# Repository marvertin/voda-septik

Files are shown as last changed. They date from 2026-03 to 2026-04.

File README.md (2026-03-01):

# voda-septik

## Dokumentace

- [OTA aktualizace](docs/ota.md)
- [Logovani a log levely](docs/logging.md)

## Kalibrace tlaku (webapp)

Modul tlaku (`main/tlak.cpp`) meri dve 4-20 mA cidla (pred filtrem / za filtrem) a hodnoty mapuje pres kalibracni polozky dostupne v konfiguracni webapp.

- `tlk_b_raw_4ma` (default `745`) - ADC RAW hodnota pred filtrem odpovidajici 4 mA.
- `tlk_b_raw_20ma` (default `3722`) - ADC RAW hodnota pred filtrem odpovidajici 20 mA.
- `tlk_b_p_min` (default `0.0`) - tlak pred filtrem [bar] pro 4 mA.
- `tlk_b_p_max` (default `10.0`) - tlak pred filtrem [bar] pro 20 mA.
- `tlk_a_raw_4ma` (default `745`) - ADC RAW hodnota za filtrem odpovidajici 4 mA.
- `tlk_a_raw_20ma` (default `3722`) - ADC RAW hodnota za filtrem odpovidajici 20 mA.
- `tlk_a_p_min` (default `0.0`) - tlak za filtrem [bar] pro 4 mA.
- `tlk_a_p_max` (default `10.0`) - tlak za filtrem [bar] pro 20 mA.
- `tlk_ema_alpha` (default `0.55`) - spolecny EMA filtr pro obe cidla.
- `tlk_hyst_bar` (default `0.02`) - spolecna hystereze [bar] pro obe cidla.
- `tlk_sample_ms` (default `100`) - spolecna perioda mereni [ms] pro obe cidla.
- `tlk_round_dec` (default `2`) - spolecny pocet desetinnych mist publikovaneho tlaku.
- `tlk_dp_100` (default `1.0`) - rozdil tlaku [bar], ktery odpovida 100 % zanesenosti filtru.

Publikovane MQTT hodnoty:
- `stav/tlak/pred_filtrem_bar`
- `stav/tlak/za_filtrem_bar`
- `stav/tlak/rozdil_filtru_bar`
- `stav/tlak/zanesenost_filtru_percent`

Doporuceny postup prvotniho nastaveni:
1. Pro kazde cidlo zvlast zmerit referencni body 4 mA/20 mA a upravit `tlk_b_*` a `tlk_a_*`.
2. Nastavit realny rozsah cidel (vychozi 0-10 bar) pomoci `tlk_b_p_min/max` a `tlk_a_p_min/max`.
3. Podle dynamiky provozu doladit spolecnou filtraci (`tlk_ema_alpha`, `tlk_hyst_bar`, `tlk_sample_ms`, `tlk_round_dec`).
4. Podle provozu filtru doladit `tlk_dp_100`, aby procenta zaneseni odpovidala realnemu stavu.

Kalibracni checklist (rychly postup):
- [ ] Zapnout debug pro tag `TLAK` a overit, ze hodnoty `raw` nekolisaji nestandardne.
- [ ] Pri referencnim bode 4 mA/20 mA nastavit kalibraci pred filtrem (`tlk_b_*`).
- [ ] Pri referencnim bode 4 mA/20 mA nastavit kalibraci za filtrem (`tlk_a_*`).
- [ ] Overit, ze tlaky odpovidaji manometru, pripadne doladit `tlk_b_p_min/max` a `tlk_a_p_min/max`.
- [ ] Doladit spolecnou filtraci (`tlk_ema_alpha`, `tlk_hyst_bar`, `tlk_sample_ms`, `tlk_round_dec`) podle pozadovane dynamiky.
- [ ] Pri znamem zanesenem stavu filtru doladit `tlk_dp_100`.

## Kalibrace objemu (webapp)

Modul objemu (`main/zasoba.cpp`) interne zmeri vysku hladiny (kalibrace `lvl_*`) a do MQTT/HA publikuje objem i vysku hladiny.

Kalibracni polozky:
- `lvl_raw_min` (default `540`) - ADC RAW hodnota odpovidajici minimalni hladine.
- `lvl_raw_max` (default `950`) - ADC RAW hodnota odpovidajici maximalni hladine.
- `lvl_h_min` (default `0.0`) - vyska hladiny [m] pro `lvl_raw_min`.
- `lvl_h_max` (default `0.290`) - vyska hladiny [m] pro `lvl_raw_max`.
- `tank_area_m2` (default `5.4`) - pudorysna plocha nadrze [m²] (pro nadrz 2 × 2.7 m).

Pouzity prepocet:
- vyska z kalibrace RAW: linearni mapovani mezi `lvl_raw_min/lvl_raw_max` a `lvl_h_min/lvl_h_max`
- objem: `objem_l = vyska_m * tank_area_m2 * 1000`

Publikovany MQTT vystup:
- `stav/zasoba/objem_l` [l]
- `stav/zasoba/hladina_m` [m]

Prakticky postup:
1. Nejdriv zkalibrovat vysku (`lvl_*`) podle realnych referencnich bodu.
2. Nastavit skutecnou plochu nadrze v `tank_area_m2`.
3. Overit v HA, ze `stav/zasoba/objem_l` a `stav/zasoba/hladina_m` odpovidaji realnemu stavu nadrze.

## Struktura mqtt topiků.

Poznamka (migrace):
- Konfiguracni polozka `mqtt_topic` byla odstranena.
- Korenny topic je nyni pevne dany v registru topiku (`main/mqtt_topics.*`) jako `voda/septik`.

## Home Assistant MQTT discovery

- Firmware po kazdem pripojeni k MQTT automaticky publikuje discovery konfiguraci pro vsechny `PUBLISH_ONLY` topicy.
- Discovery konfigurace jsou publikovane jako retained zpravy pod vetvi `homeassistant/.../config`.
- Device je seskupene pod identifikatorem `voda_septik_esp32`.
- Pro odebrani starych entit je potreba smazat retained discovery topicy na brokeru.

```
voda/septik                         Voda v nadrzi (byvaly septik), vcetne dalsich budoucih pouziti (napr. bazen)

├── stav/
│    ├── teplota/
│    │    ├── voda                  [°C] Aktuální teplota vody v nádrži. HA: sensor (device_class: temperature)
│    │    └── vzduch                [°C] Aktuální teplota vzduchu v šachtě u potrubí v blízkosti tlakové nádoby. HA: sensor (device_class: temperature)
│    ├── zasoba/
│    │    ├── objem_l               [l] Aktuální objem vody v nádrži. HA: sensor (state_class: measurement)
│    │    └── hladina_m             [m] Aktuální výška hladiny vody v nádrži. HA: sensor (state_class: measurement)
│    ├── cerpani/
│    │    ├── prutok_l_min          [l/min] Aktuální průtok vody. HA: sensor (state_class: measurement)
│    │    ├── cerpano_celkem_l      [l] Celkové vyčerpané množství vody od počátku. HA: sensor (state_class: total_increasing)
│    │    └── pumpa/
│    │         ├── bezi             [bool] Příznak ano/ne (0/1), zda čerpadlo běží. HA: binary_sensor (device_class: running)
│    │         ├── vykon_cinny_w    [W] Aktuální činný výkon. HA: sensor (device_class: power)
│    │         ├── jalovy_vykon_var [var] Aktuální jalový výkon. HA: sensor
│    │         ├── cosfi            [-] Aktuální účiník. HA: sensor
│    │         ├── proud_a          [A] Aktuální proud protékaný čerpadlem. HA: sensor (device_class: current)
│    │         ├── napeti_v         [V] Aktuální napětí na čerpadle. HA: sensor (device_class: voltage)
│    │         ├── energie_cinna_kwh [kWh] Celkové množství spotřebované činné energie. HA: sensor (device_class: energy, state_class: total_increasing)
│    │         └── energie_jalova_kvarh [kvarh] Celkové množství spotřebované jalové energie. HA: sensor (state_class: total_increasing)
│    └── tlak/
│         ├── pred_filtrem_bar      [bar] Aktuální tlak vody před filtrem. HA: sensor (device_class: pressure)
│         ├── za_filtrem_bar        [bar] Aktuální tlak vody za filtrem. HA: sensor (device_class: pressure)
│         ├── rozdil_filtru_bar     [bar] Rozdíl tlaku před a za filtrem. HA: sensor (state_class: measurement)
│         └── zanesenost_filtru_percent [%] Odhad zanesení filtru v procentech (odvozeno z rozdílu tlaků). HA: sensor
│
├── system/
│    ├── status                     [-] online/offline (řešeno přes LWT). HA: binary_sensor (device_class: connectivity)
│    ├── boot_mode                  [text] Rezim startu firmware: `ota` (pending verify) / `normal`
│    ├── ota/event                  [text] Prubeh OTA operace (start/download/rebooting/confirmed/error_...)
│    ├── ota/progress               [%] Prubeh OTA stahovani a zapisu (0-100)
│    ├── reboot_reason              [text] Důvod posledního rebootu (esp_reset_reason). HA: sensor
│    ├── reboot_counter             [count] Počet rebootů od instalace. HA: sensor (state_class: total_increasing)
│    └── last_disconnect_duration_s [s] Doba posledního výpadku spojení. HA: sensor
│
├── diag/
│    ├── fw_version                 [text] Verze firmware. HA: sensor
│    ├── build_timestamp            [datetime] Datum a čas sestavení firmware. HA: sensor
│    ├── git_hash                   [text] Git hash verze firmware. HA: sensor
│    ├── uptime_s                   [s] Jak dlouho zařízení běží. HA: sensor (state_class: total_increasing)
│    ├── wifi_rssi_dbm              [dBm] Síla WiFi signálu. HA: sensor (device_class: signal_strength)
│    ├── wifi_reconnect_try         [count] Počet pokusů o reconnect k WiFi. HA: sensor (state_class: total_increasing)
│    ├── wifi_reconnect_success     [count] Počet úspěšných reconnectů k WiFi. HA: sensor (state_class: total_increasing)
│    ├── mqtt_reconnects            [count] Počet reconnectů k MQTT brokeru. HA: sensor (state_class: total_increasing)
│    ├── last_mqtt_rc               [code] Poslední návratový kód MQTT klienta. HA: sensor
│    ├── heap_free_b                [B] Aktuální počet volných bajtů na heapu. HA: sensor (device_class: data_size)
│    ├── heap_min_free_b            [B] Nejmenší zaznamenaná hodnota volného heapu od startu. HA: sensor (device_class: data_size)
│    ├── esp_vcc_mv                 [mV] Napájecí napětí ESP. HA: sensor (device_class: voltage)
│    ├── nvs_errors                 [count] Počet chyb při práci s NVS. HA: sensor (state_class: total_increasing)
│    └── teplota_scan               [json] Prubezny report nalezenych DS18B20 adres, teplot a mapovani na konfiguraci
│
├── cmd/
│    ├── reboot                     [-] Reboot zařízení, čímž se vypnou všechny debugy. HA: button
│    ├── webapp/start               [-] Nastartování konfigurační aplikace. Implicitně je vypnutá, po startu se sama po 2 hodinách vypne. HA: button
│    ├── webapp/stop                [-] Vypnutí webové aplikace. HA: button
│    ├── debug/start                [-] Nastartování debug režimu, začnou se produkovat debug data. HA: button
│    ├── debug/stop                 [-] Zastavení debug režimu. HA: button
│    ├── log/level                  [text] Nastaveni log levelu per tag (payload: tag=level)
│    ├── ota/start                  [url] URL na binarni obraz firmware (http/https)
│    ├── ota/confirm                [-] Rucni potvrzeni nahraneho firmware po overeni funkcnosti
│    └── teplota/scan               [bool] Zapnuti/vypnuti periodickeho skenovani DS18B20 adres (1=true, 0=false)
│
└── debug

## Ovladani pres Mosquitto CLI

Podrobny navod k logovani je v dokumentu [Logovani a log levely](docs/logging.md).

Pro pohodlne ovladani je v projektu jednotny interaktivni skript:

```bash
zalevaci
```

Pokud jeste nemas aktivni `direnv`, udelej jednorazove:

```bash
direnv allow
```

Potom bude `tools/` automaticky v `PATH` pri vstupu do adresare projektu a prikaz `zalevaci` bude dostupny primo.

Napoveda a neinteraktivni rezim:

```bash
zalevaci --help
```

Priklady (vhodne pro skripty/CI):

```bash
# command publish
zalevaci cmd reboot

# log level
zalevaci log --tag mqtt_cmd --level DEBUG

# vycisteni retained cmd topiku
zalevaci clear-retained

# vypis nalezenych log tagu
zalevaci tags
```

Skript:
- pouziva default parametry: `mqtt.home.arpa:1883`, uzivatel `ha`, `qos=1`, root `voda/septik`,
- cte heslo ze souboru `~/.voda-septik/mqtt_password`,
- kdyz soubor neexistuje, zepta se na heslo a ulozi ho (`chmod 600`),
- nabidne menu pro command topiky (`reboot`, `webapp/start`, `debug/start|stop`, ...),
- umi nastavit log level (vcetne volby tagu nalezenych ve zdrojacich),
- umi zapnout/vypnout scan teplotnich cidel (`cmd/teplota/scan`),
- umi vycistit retained command topiky,
- umi projit OTA flow (HTTP server + `cmd/ota/start` + potvrzeni).

Volitelne lze prepsat parametry pres promenne prostredi:

```bash
MQTT_HOST=mqtt.home.arpa MQTT_PORT=1883 MQTT_USER=ha TOPIC_ROOT=voda/septik zalevaci
```

Pokud je potreba smazat stare retained command zpravy na brokeru, pouzij volbu `Vycistit retained cmd/*` v menu skriptu `zalevaci`.

Nize jsou priklady pro `mosquitto_sub` a `mosquitto_pub`.

Nejdriv si nastav promenne (uprav podle sveho brokeru):

```bash
MQTT_HOST=192.168.1.10
MQTT_PORT=1883
MQTT_USER="uzivatel"
MQTT_PASS="heslo"
TOPIC_ROOT="voda/septik"
```

### Odběr vsech dat ze zarizeni

```bash
mosquitto_sub -h "$MQTT_HOST" -p "$MQTT_PORT" -u "$MQTT_USER" -P "$MQTT_PASS" -v -t "$TOPIC_ROOT/#"
```

### Odeslani commandu

`cmd/reboot` (restart zarizeni):

```bash
mosquitto_pub -h "$MQTT_HOST" -p "$MQTT_PORT" -u "$MQTT_USER" -P "$MQTT_PASS" -t "$TOPIC_ROOT/cmd/reboot" -m "1"
```

`cmd/webapp` (spusti konfiguracni web):

```bash
mosquitto_pub -h "$MQTT_HOST" -p "$MQTT_PORT" -u "$MQTT_USER" -P "$MQTT_PASS" -t "$TOPIC_ROOT/cmd/webapp" -m "on"
```

`cmd/webapp` (zastavi konfiguracni web):

```bash
mosquitto_pub -h "$MQTT_HOST" -p "$MQTT_PORT" -u "$MQTT_USER" -P "$MQTT_PASS" -t "$TOPIC_ROOT/cmd/webapp" -m "off"
```

`cmd/debug` (zapne debug publikaci):

```bash
mosquitto_pub -h "$MQTT_HOST" -p "$MQTT_PORT" -u "$MQTT_USER" -P "$MQTT_PASS" -t "$TOPIC_ROOT/cmd/debug" -m "on"
```

`cmd/debug` (vypne debug publikaci):

```bash
mosquitto_pub -h "$MQTT_HOST" -p "$MQTT_PORT" -u "$MQTT_USER" -P "$MQTT_PASS" -t "$TOPIC_ROOT/cmd/debug" -m "off"
```

`cmd/ota/start` (spusti OTA z URL):

```bash
mosquitto_pub -h "$MQTT_HOST" -p "$MQTT_PORT" -u "$MQTT_USER" -P "$MQTT_PASS" -q 1 -t "$TOPIC_ROOT/cmd/ota/start" -m "http://192.168.1.10:8000/voda-septik.bin"
```

`cmd/ota/confirm` (potvrdi novy firmware po rebootu):

```bash
mosquitto_pub -h "$MQTT_HOST" -p "$MQTT_PORT" -u "$MQTT_USER" -P "$MQTT_PASS" -q 1 -t "$TOPIC_ROOT/cmd/ota/confirm" -m "1"
```

`cmd/teplota/scan` (zapne periodicky scan DS18B20 adres a report na `diag/teplota_scan`):

```bash
mosquitto_pub -h "$MQTT_HOST" -p "$MQTT_PORT" -u "$MQTT_USER" -P "$MQTT_PASS" -q 1 -t "$TOPIC_ROOT/cmd/teplota/scan" -m "1"
```

`cmd/teplota/scan` (vypne scan):

```bash
mosquitto_pub -h "$MQTT_HOST" -p "$MQTT_PORT" -u "$MQTT_USER" -P "$MQTT_PASS" -q 1 -t "$TOPIC_ROOT/cmd/teplota/scan" -m "0"
```

### Odběr debug vetve

```bash
mosquitto_sub -h "$MQTT_HOST" -p "$MQTT_PORT" -u "$MQTT_USER" -P "$MQTT_PASS" -v -t "$TOPIC_ROOT/debug/#"
```

## OTA helper skript

Podrobny navod k OTA je v dokumentu [OTA aktualizace](docs/ota.md).

V projektu je interaktivni helper (soucast `zalevaci`), ktery:
- spusti jednoduchy HTTP server nad vybranym `.bin` souborem,
- posle MQTT command `cmd/ota/start` s URL na firmware,
- po rebootu se zepta, zda je firmware v poradku,
- pri potvrzeni posle `cmd/ota/confirm`.

Spusteni:

```bash
zalevaci
```

V menu zvol `OTA flow`.

## Architektura site (po refaktoru)

- `components/network_core/network_init.*`
    - Orchestrace site: WiFi init (STA/AP), MQTT lifecycle, event handlery, retry timery (neblokujici).
    - Sbira runtime data (wifi/ip/mqtt) a publikuje callback `network_event_t`.

- `components/network_core/network_event.*`
    - Definice `network_event_t` + vyhodnoceni `system_network_level_t`.
    - Vyroba sitoveho eventu primo uvnitr `network_core` vcetne reconnect counteru.

- `components/network_core/network_mqtt_config.*`
    - Validace `mqtt_uri` a bezpecne ulozeni `uri/user/pass` pro MQTT klienta.
    - Poskytuje read-only pristup na pripravenou konfiguraci.

- `components/network_core/mqtt_publish.*`
    - Samostatna vrstva pro publikaci zprav (`mqtt_publish`) mimo init/lifecycle.
    - Pouziva aktivni MQTT klient handle z `network_init`.

- `main/network_event_bridge.*`
    - Odebira `network_event_t` callback z `network_core`.
    - Bali jej do `app_event_t` a publikuje `EVT_NETWORK` do interni event queue.

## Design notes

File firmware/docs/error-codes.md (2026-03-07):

# Error kódy (`Exxx`) – mapování a pravidla

## Pravidla

- Formát kódu je `E` + 3 číslice.
- První číslice určuje modul (rozsah `E1xx` až `E9xx`).
- V rámci modulu se kódy přidělují postupně bez mezer (`E101`, `E102`, ...).
- Kódy musí být v projektu unikátní.
- `cpp_app_main` v `main/voda-septik.cpp` začíná na `E101`.

## Mapa modulů

| Modul | Soubory | Rozsah |
|---|---|---|
| `cpp_app_main` | `main/voda-septik.cpp` | `E101–E199` |
| `network_core` | `components/network_core/network_init.cpp` | `E201–E299` |
| `config_store` | `components/config_store/config_store.cpp` | `E301–E399` |
| `restart_info` | `main/restart_info.cpp` | `E401–E499` |
| `mqtt_runtime` | `main/mqtt_commands.cpp`, `main/mqtt_publisher_task.cpp` | `E501–E599` |
| `state_manager` | `main/state_manager.cpp` | `E601–E699` |
| `sensor_stack` | `main/adc_shared.cpp`, `main/prutokomer.cpp`, `main/teplota.cpp`, `main/tlak.cpp`, `main/tlak2.cpp`, `main/zasoba.cpp` | `E701–E799` |
| `config_items` | `main/network_config.cpp`, `main/system_config.cpp` | `E801–E899` |
| `display_lcd` | `main/lcd.cpp` | `E901–E999` |

## Kontrola duplicit

Použij projektové hledání na výraz `\bE\d{3}\b` a ověř, že každý kód je použit právě jednou.

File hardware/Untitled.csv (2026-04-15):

Název sítě | Třída sítí | Délka sítě (mm) | Počet prokovů | Délka prokovu (mm) | Délka spoje (mm) | Délka od plošky po čip (mm) | Počet plošek | F.Cu (mm) | B.Cu (mm)
GND | Napájení a Default | 434.6058 | 7 | 10.8150 | 423.7908 | 0.0000 | 32 | 166.2069 | 257.5838
+5V | Napájení a Default | 150.7235 | 1 | 1.5450 | 149.1785 | 0.0000 | 7 | 70.7569 | 78.4217
/hladina 4-20mA | Default | 29.7595 | 0 | 0.0000 | 29.7595 | 0.0000 | 3 | 0.0000 | 29.7595
/tlak_za_filtrem | Default | 15.5075 | 0 | 0.0000 | 15.5075 | 0.0000 | 3 | 0.0000 | 15.5075
/teploměry | Default | 19.2966 | 0 | 0.0000 | 19.2966 | 0.0000 | 3 | 0.0000 | 19.2966
/průtok | Default | 13.7500 | 0 | 0.0000 | 13.7500 | 0.0000 | 3 | 0.0000 | 13.7500
Net-(C1-Pad1) | Default | 11.1911 | 0 | 0.0000 | 11.1911 | 0.0000 | 2 | 0.0000 | 11.1911
Net-(D2-K) | Default | 51.5259 | 0 | 0.0000 | 51.5259 | 0.0000 | 6 | 0.0000 | 51.5259
Net-(D2-A) | Default | 11.3450 | 0 | 0.0000 | 11.3450 | 0.0000 | 2 | 0.5000 | 10.8450
Net-(D4-K) | Default | 48.0354 | 0 | 0.0000 | 48.0354 | 0.0000 | 4 | 0.0000 | 48.0354
Net-(D5-K) | Default | 40.9083 | 0 | 0.0000 | 40.9083 | 0.0000 | 4 | 0.0000 | 40.9083
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

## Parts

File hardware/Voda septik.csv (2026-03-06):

Reference | Qty | Value | DNP | Exclude from BOM | Exclude from Board | Footprint | Datasheet
BT1 | 1 | 3V |  |  |  | Battery:BatteryHolder_Keystone_1058_1x2032 | ~
D1 | 1 | red |  |  |  | LED_THT:LED_D5.0mm | ~
R1 | 1 | 1k |  |  |  | Resistor_THT:R_Axial_DIN0309_L9.0mm_D3.2mm_P12.70mm_Horizontal | ~

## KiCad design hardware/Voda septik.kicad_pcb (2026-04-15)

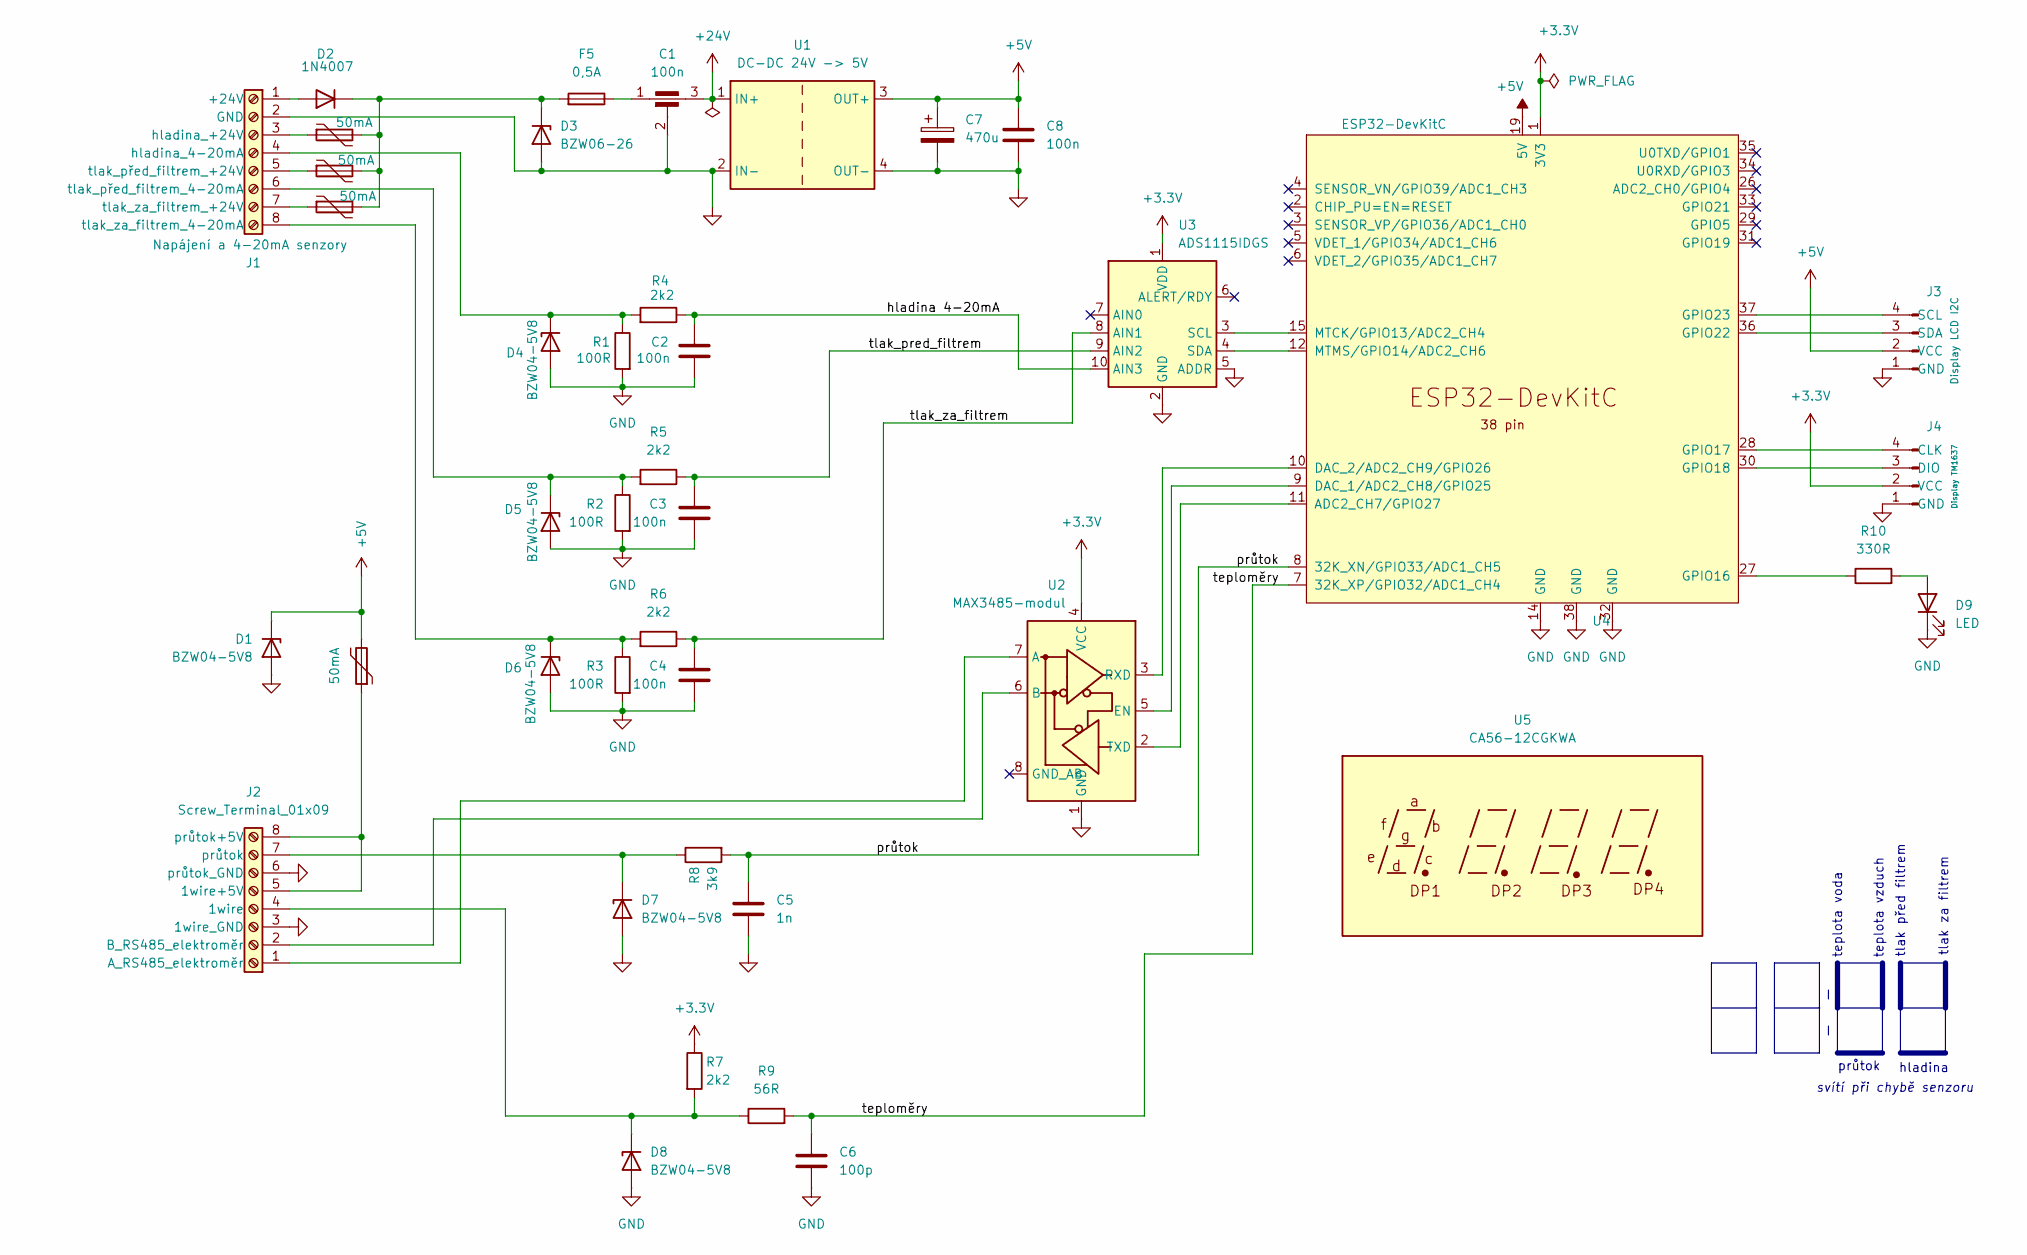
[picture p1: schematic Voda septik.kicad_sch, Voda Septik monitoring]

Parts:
C1: 100n; Odruseni_3x_2.54mm
C2, C3, C4, C8: 100n; C_Disc_D5.0mm_W2.5mm_P5.00mm
C5: 1n; C_Disc_D5.0mm_W2.5mm_P5.00mm
C6: 100p; C_Disc_D5.0mm_W2.5mm_P5.00mm
C7: 470u; CP_Radial_D10.0mm_P5.00mm
D1, D4, D5, D6, D7, D8: BZW04-5V8; D_DO-15_P2.54mm_Vertical_AnodeUp
D2: 1N4007; D_DO-15_P2.54mm_Vertical_AnodeUp
D3: BZW06-26; D_DO-15_P2.54mm_Vertical_AnodeUp
D9: LED; LED_D3.0mm
F1, F2, F3, F4: 50mA; Fuse_Disc_D8.3_W3.8_P5.1
F5: 0,5A; Fuse_Axial_L11mm_D3.9mm_P15.24mm_Horizontal
J1: Napájení a 4-20mA senzory; Svorky_EB147A_8_5.08
J2: Screw_Terminal_01x09; Svorky_EB147A_8_5.08
J3: Display LCD I2C; PinHeader_1x04_P2.54mm_Vertical
J4: Display TM1637; PinHeader_1x04_P2.54mm_Vertical
R1, R2, R3: 100R; R_Axial_DIN0207_L6.3mm_D2.5mm_P2.54mm_Vertical
R4, R5, R6, R7: 2k2; R_Axial_DIN0207_L6.3mm_D2.5mm_P2.54mm_Vertical
R8: 3k9; R_Axial_DIN0207_L6.3mm_D2.5mm_P2.54mm_Vertical
R9: 56R; R_Axial_DIN0207_L6.3mm_D2.5mm_P2.54mm_Vertical
R10: 330R; R_Axial_DIN0207_L6.3mm_D2.5mm_P2.54mm_Vertical
U1: DC-DC 24V -> 5V; LM2596 DC-DC HW-411
U2: MAX3485-modul
U3: ADS1115IDGS; ADS1115_modul_vertical
U4: ESP32-DevKitC
U5: CA56-12CGKWA; DISPLAY_clok_MOUNT_4xM3

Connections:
+3.3V: J4.2 (VCC), R7.1, U2.4 (VCC), U3.1 (VDD), U4.1 (3V3)
+5V: C7.1, C8.1, D1.1 (K), F4.2, J3.2 (VCC), U1.3 (OUT+), U4.19 (5V)
+24V: C1.3, U1.1 (IN+)
/hladina 4-20mA: C2.1, R4.1, U3.10 (AIN3)
/průtok: C5.1, R8.2, U4.8 (32K_XN/GPIO33/ADC1_CH5)
/teploměry: C6.1, R9.2, U4.7 (32K_XP/GPIO32/ADC1_CH4)
/tlak_za_filtrem: C4.1, R6.1, U3.8 (AIN1)
GND: C1.2, C2.2, C3.2, C4.2, C5.2, C6.2, C7.2, C8.2, D1.2 (A), D3.2 (A), D4.2 (A), D5.2 (A), D6.2 (A), D7.2 (A), D8.2 (A), D9.1 (K), J1.2 (GND), J2.3 (1wire_GND), J2.6 (průtok_GND), J3.1 (GND), J4.1 (GND), R1.2, R2.2, R3.2, U1.2 (IN-), U1.4 (OUT-), U2.1 (GND), U3.2 (GND), U3.5 (ADDR), U4.14 (GND), U4.32 (GND), U4.38 (GND)
unnamed: C1.1, F5.2
unnamed: D2.2 (A), J1.1 (+24V)
unnamed: D2.1 (K), D3.1 (K), F1.2, F2.2, F3.2, F5.1
unnamed: D4.1 (K), J1.4 (hladina_4-20mA), R1.1, R4.2
unnamed: D5.1 (K), J1.6 (tlak_před_filtrem_4-20mA), R2.1, R5.2
unnamed: D6.1 (K), J1.8 (tlak_za_filtrem_4-20mA), R3.1, R6.2
unnamed: D7.1 (K), J2.7 (průtok), R8.1
unnamed: D8.1 (K), J2.4 (1wire), R7.2, R9.1
unnamed: D9.2 (A), R10.2
unnamed: F1.1, J1.3 (hladina_+24V)
unnamed: F2.1, J1.5 (tlak_před_filtrem_+24V)
unnamed: F3.1, J1.7 (tlak_za_filtrem_+24V)
unnamed: F4.1, J2.5 (1wire+5V), J2.8 (průtok+5V)
unnamed: J2.1 (A_RS485_elektroměr), U2.7 (A)
unnamed: J2.2 (B_RS485_elektroměr), U2.6 (B)
unnamed: J3.4 (SCL), U4.37 (GPIO23)
unnamed: J3.3 (SDA), U4.36 (GPIO22)
unnamed: J4.4 (CLK), U4.28 (GPIO17)
unnamed: J4.3 (DIO), U4.30 (GPIO18)
unnamed: U2.5 (EN), U4.9 (DAC_1/ADC2_CH8/GPIO25)
unnamed: U2.3 (RXD), U4.10 (DAC_2/ADC2_CH9/GPIO26)
unnamed: U2.2 (TXD), U4.11 (ADC2_CH7/GPIO27)
unnamed: C3.1, R5.1, U3.9 (AIN2)
unnamed: U3.3 (SCL), U4.15 (MTCK/GPIO13/ADC2_CH4)
unnamed: U3.4 (SDA), U4.12 (MTMS/GPIO14/ADC2_CH6)
unnamed: R10.1, U4.27 (GPIO16)

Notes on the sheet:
teplota vzduch
průtok
tlak před filtrem
svítí při chybě senzoru
tlak za filtrem
teplota voda
hladina

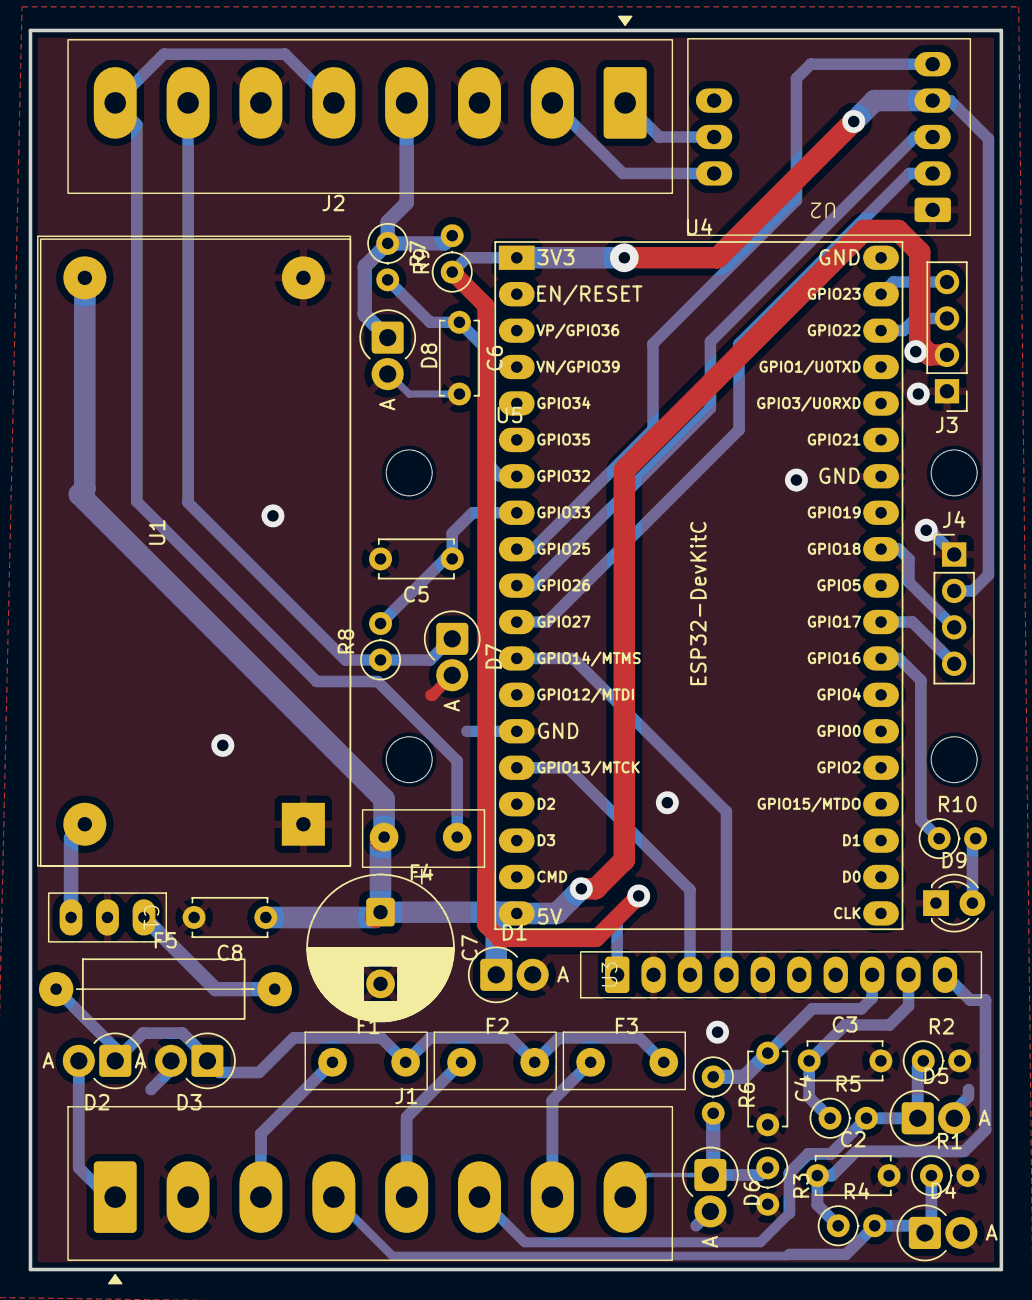
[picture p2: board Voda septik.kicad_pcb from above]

Board: 2 copper layers, 67.7 x 86.4 mm, 41 parts (0 on the bottom side), 34 nets.

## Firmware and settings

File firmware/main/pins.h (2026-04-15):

#pragma once

#include "driver/gpio.h"
#include <esp_adc/adc_oneshot.h>

static const gpio_num_t STATUS_LED_GPIO = GPIO_NUM_23;           // GPIO23
static const gpio_num_t AUX_LED_GPIO = GPIO_NUM_4;              // GPIO4

static const gpio_num_t TM1637_CLK_GPIO = GPIO_NUM_18;          // GPIO18
static const gpio_num_t TM1637_DIO_GPIO = GPIO_NUM_19;          // GPIO19

static const gpio_num_t DISPLAY_I2C_SDA_GPIO = GPIO_NUM_22;             // GPIO22
static const gpio_num_t DISPLAY_I2C_SCL_GPIO = GPIO_NUM_21;             // GPIO21

static const gpio_num_t FLOW_SENSOR_GPIO = GPIO_NUM_26;         // GPIO26
static const gpio_num_t FLOW_SIMULATOR_GPIO = GPIO_NUM_25;      // GPIO25
static const gpio_num_t BOOT_BUTTON_GPIO = GPIO_NUM_0;          // GPIO0
static const gpio_num_t TEMPERATURE_SENSOR_GPIO = GPIO_NUM_27;  // GPIO27
static const gpio_num_t RS485_RX_GPIO = GPIO_NUM_17;        // GPIO17 (MAX3485 TXD)
static const gpio_num_t RS485_TX_GPIO = GPIO_NUM_16;        // GPIO16 (MAX3485 RXD)
static const gpio_num_t RS485_EN_GPIO = GPIO_NUM_5;         // GPIO5 (MAX3485 EN)

static const adc_channel_t LEVEL_SENSOR_ADC_CHANNEL = ADC_CHANNEL_0;          // ADC1_CH6 (GPIO34)

static const adc_channel_t PRESSURE_SENSOR_BEFORE_ADC_CHANNEL = ADC_CHANNEL_6; // ADC1_CH4 (GPIO32)
static const adc_channel_t PRESSURE_SENSOR_AFTER_ADC_CHANNEL = ADC_CHANNEL_7;  // ADC1_CH5 (GPIO33)

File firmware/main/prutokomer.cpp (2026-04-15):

#ifdef __cplusplus
extern "C" {
#endif

#include "esp_log.h"
#include "freertos/FreeRTOS.h"
#include "freertos/task.h"
#include "esp_timer.h"
#include "esp_task_wdt.h"
#include "driver/gpio.h"

#ifdef __cplusplus
}
#endif

#include "pins.h"
#include "sensor_events.h"
#include "flash_monotonic_counter.h"
#include "config_store.h"
#include "app_error_check.h"
#include "debug_mqtt.h"
#include <math.h>

#define TAG "prutokomer"

static constexpr int32_t FLOW_DEFAULT_PULSES_PER_LITER = 38; // F = 4.5 * Q, Q v l/min
static constexpr int32_t FLOW_MIN_PULSES_PER_LITER = 1;
static constexpr int32_t FLOW_MAX_PULSES_PER_LITER = 200;
static constexpr uint32_t COUNTER_INCREMENT_LITERS = 1; // Kolik litrů odpovídá jednomu kroku v monotonic counteru
static constexpr TickType_t FLOW_SAMPLE_PERIOD = pdMS_TO_TICKS(200);
static constexpr UBaseType_t FLOW_TASK_STACK_SIZE = 4096;
static constexpr uint8_t FLOW_LOG_EVERY_N_SAMPLES = 5;
static constexpr uint32_t FLOW_PULSE_TIMESTAMPS_BUFFER_SIZE = 128;
static constexpr int64_t FLOW_TARGET_WINDOW_US = 1500000; // cílové okno historie pro odhad průtoku
static constexpr uint32_t FLOW_MIN_INTERVALS_FOR_ESTIMATE = 4;
static constexpr uint32_t FLOW_ZERO_TIMEOUT_US = 3000000; // pokud bez impulsu, průtok = 0

static constexpr bool FLOW_SIMULATOR_ENABLED = false;
static constexpr uint32_t FLOW_SIMULATED_PULSE_WIDTH_US = 1000;
static constexpr const char *FLOW_SIMULATOR_PERIODIC_TIMER_NAME = "flow_sim_period";
static constexpr const char *FLOW_SIMULATOR_PULSE_OFF_TIMER_NAME = "flow_sim_off";
static constexpr TickType_t FLOW_SIMULATOR_PROFILE_UPDATE_PERIOD = pdMS_TO_TICKS(200);
static constexpr UBaseType_t FLOW_SIMULATOR_TASK_STACK_SIZE = 3072;

static const config_item_t FLOW_PULSES_PER_LITER_ITEM = {
    .key = "flow_pulses_l", .label = "Prutokomer pulsy na litr", .description = "Kalibracni konstanta prutokomeru: kolik impulsu odpovida jednomu litru.",
    .type = CONFIG_VALUE_INT32, .default_string = nullptr, .default_int = FLOW_DEFAULT_PULSES_PER_LITER, .default_float = 0.0f, .default_bool = false,
    .max_string_len = 0, .min_int = FLOW_MIN_PULSES_PER_LITER, .max_int = FLOW_MAX_PULSES_PER_LITER, .min_float = 0.0f, .max_float = 0.0f,
};

static const char *FLOW_COUNTER_PARTITION_LABEL = "flow_data0";

// Kruhový buffer posledních N časů impulsů pro výpočet průtoku
static int64_t s_pulse_timestamps[FLOW_PULSE_TIMESTAMPS_BUFFER_SIZE];
static volatile uint32_t s_pulse_write_idx = 0;

// sdílený counter z ISR
static volatile uint32_t pulse_count = 0;
static portMUX_TYPE s_pulse_count_mux = portMUX_INITIALIZER_UNLOCKED;
static FlashMonotonicCounter s_flow_counter;
static uint64_t s_persisted_counter_steps = 0;
static uint64_t s_unpersisted_pulses = 0;
static uint32_t s_flow_pulses_per_liter = static_cast<uint32_t>(FLOW_DEFAULT_PULSES_PER_LITER);
static uint32_t s_pulses_per_counter_increment =
    static_cast<uint32_t>(FLOW_DEFAULT_PULSES_PER_LITER) * COUNTER_INCREMENT_LITERS;
static esp_timer_handle_t s_flow_simulator_periodic_timer = nullptr;
static esp_timer_handle_t s_flow_simulator_pulse_off_timer = nullptr;
static uint32_t s_flow_simulator_pulse_width_us = FLOW_SIMULATED_PULSE_WIDTH_US;
static float s_flow_simulator_current_l_min = 0.0f;
static bool s_prutok_zaokrouhleny_valid = false;
static float s_prutok_zaokrouhleny = 0.0f;

typedef struct {
    const char *name;
    float start_l_min;
    float end_l_min;
    TickType_t duration_ticks;
} flow_simulator_profile_step_t;

static const flow_simulator_profile_step_t FLOW_SIMULATOR_PROFILE[] = {
    {.name = "stopped",        .start_l_min = 0.0f,  .end_l_min = 0.0f,  .duration_ticks = pdMS_TO_TICKS(3000)},
    {.name = "slow_rise",      .start_l_min = 0.0f,  .end_l_min = 8.0f,  .duration_ticks = pdMS_TO_TICKS(12000)},
    {.name = "fast_rise",      .start_l_min = 8.0f,  .end_l_min = 55.0f, .duration_ticks = pdMS_TO_TICKS(5000)},
    {.name = "hold_high",      .start_l_min = 55.0f, .end_l_min = 55.0f, .duration_ticks = pdMS_TO_TICKS(5000)},
    {.name = "slow_fall",      .start_l_min = 55.0f, .end_l_min = 18.0f, .duration_ticks = pdMS_TO_TICKS(10000)},
    {.name = "fast_stop",      .start_l_min = 18.0f, .end_l_min = 0.0f,  .duration_ticks = pdMS_TO_TICKS(4000)},
    {.name = "stopped_again",  .start_l_min = 0.0f,  .end_l_min = 0.0f,  .duration_ticks = pdMS_TO_TICKS(4000)},
    {.name = "quick_restart",  .start_l_min = 0.0f,  .end_l_min = 42.0f, .duration_ticks = pdMS_TO_TICKS(3000)},
    {.name = "hold_medium",    .start_l_min = 42.0f, .end_l_min = 42.0f, .duration_ticks = pdMS_TO_TICKS(5000)},
    {.name = "slow_taper",     .start_l_min = 42.0f, .end_l_min = 6.0f,  .duration_ticks = pdMS_TO_TICKS(8000)},
    {.name = "hold_low",       .start_l_min = 6.0f,  .end_l_min = 6.0f,  .duration_ticks = pdMS_TO_TICKS(5000)},
};

void prutokomer_register_config_items(void)
{
    APP_ERROR_CHECK("E706", config_store_register_item(&FLOW_PULSES_PER_LITER_ITEM));
}

static void load_flow_config(void)
{
    const int32_t configured = config_store_get_i32_item(&FLOW_PULSES_PER_LITER_ITEM);
    const int32_t clamped =
        (configured < FLOW_MIN_PULSES_PER_LITER)
            ? FLOW_MIN_PULSES_PER_LITER
            : ((configured > FLOW_MAX_PULSES_PER_LITER)
                   ? FLOW_MAX_PULSES_PER_LITER
                   : configured);

    s_flow_pulses_per_liter = static_cast<uint32_t>(clamped);
    s_pulses_per_counter_increment = s_flow_pulses_per_liter * COUNTER_INCREMENT_LITERS;
}

// ISR handler - počítá pulsy a ukládá časy do bufferu
static void IRAM_ATTR flow_isr_handler(void *arg) {
    (void)arg;
    int64_t timestamp = esp_timer_get_time();
    
    // Počítat pulsy pro celkový objem
    portENTER_CRITICAL_ISR(&s_pulse_count_mux);
    pulse_count += 1;
    portEXIT_CRITICAL_ISR(&s_pulse_count_mux);

    s_pulse_timestamps[s_pulse_write_idx] = timestamp;
    s_pulse_write_idx = (s_pulse_write_idx + 1) % FLOW_PULSE_TIMESTAMPS_BUFFER_SIZE;
}

static uint32_t get_and_clear_pulse_count(void)
{
    uint32_t count = 0;
    portENTER_CRITICAL(&s_pulse_count_mux);
    count = pulse_count;
    pulse_count = 0;
    portEXIT_CRITICAL(&s_pulse_count_mux);
    return count;
}

static void flow_pulse_simulator_off_callback(void *arg)
{
    (void)arg;
    gpio_set_level(FLOW_SIMULATOR_GPIO, 0);
}

static void flow_pulse_simulator_periodic_callback(void *arg)
{
    (void)arg;

    gpio_set_level(FLOW_SIMULATOR_GPIO, 1);
    esp_err_t pulse_off_result = esp_timer_start_once(s_flow_simulator_pulse_off_timer,
                                                      s_flow_simulator_pulse_width_us);
    if (pulse_off_result != ESP_OK) {
        gpio_set_level(FLOW_SIMULATOR_GPIO, 0);
    }
}

static esp_err_t stop_flow_simulator_timer(esp_timer_handle_t timer)
{
    if (timer == nullptr) {
        return ESP_OK;
    }

    const esp_err_t stop_result = esp_timer_stop(timer);
    if (stop_result == ESP_OK || stop_result == ESP_ERR_INVALID_STATE) {
        return ESP_OK;
    }
    return stop_result;
}
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

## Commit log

2026-02-15 Výpis ota partišnů.
    [partitions.csv]
2026-02-25 Led nesmí blikat, když máme mqtt.
2026-02-25 Ledka hezky poblikává.
2026-02-26 Obíhající segmenty při flow.
2026-02-26 SDkconfig změněný de gitu.
2026-03-01 ADC čtení je teď lepší.
2026-03-02 přesun pod firmware
    [partitions.csv]
2026-03-06 Schéma, ale jen té krabičky.
    [Voda septik.csv, Voda septik.kicad_pcb, Voda septik.kicad_sch]
2026-03-07 LED je na jiném PIN
2026-03-07 ADC přesměrovat.
2026-03-08 Doladění průtoku a schematu.
    [Voda septik.kicad_sch]
2026-03-08 Upravit schéma podle skutečnosti.
    [Voda septik.kicad_sch]
2026-03-19 Úprava schématu, asi popisky.
    [Voda septik.kicad_sch]
2026-04-15 Dokončení schématu a návrhu PCB o stavu, který byl poslán do výroby.
    [Untitled.csv, Voda septik.kicad_pcb, Voda septik.kicad_sch]
2026-04-15 Změna názvu pkonstanty pinů úrp display, prootže přijdou i jiné I2C
2026-10-13 Evaluate disc filter pressure loss in flow-qualified windows
2026-10-13 Record confirmed v3.0.0 filter firmware deployment and remaining HA work
2026-10-13 Record deployed and verified Home Assistant filter package on amur
